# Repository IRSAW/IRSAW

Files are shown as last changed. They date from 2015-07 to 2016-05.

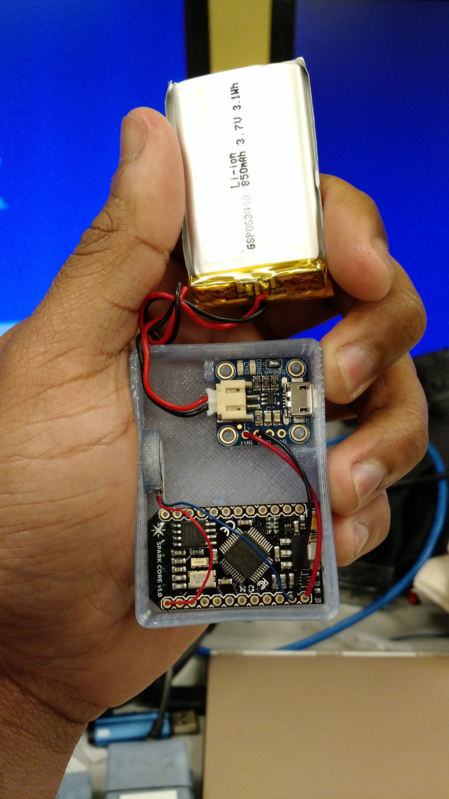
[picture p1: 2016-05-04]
Wearable Components Designs and Files for printing/Actuator Images and Diagrams/Finished Spark Core based actuator box.jpg

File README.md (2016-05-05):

# IRSAW
Intel RealSense Spatial Awareness Wearable 

This project is about augmenting the sense of the visually impaired using a wearable which gives vibrotactile feedback 
on the body to make them aware about their surroundings.  
A depth camera is used to see what is in front of a person and the vibration motors on the body notify the person 
about where the object is in the front based on what the camera sees. 

#This branch of IRSAW is highly modified which a lot of changes.

The changes are listed below

1.	Using Intel RealSense Cross Platform API (librealsense) to capture camera data instead of the DCM and the SDK, you don’t need to install anything to use the camera now.

2.	Ported to Visual Studio 2013. librealsense is not compatible with VS 2012

3.	Ported to Cinder 0.9.0 from 0.8.6

4.	You don’t have to build a Vibration Actuator with a button. All the Vibration Actuators are made the same, but the code uploaded to every single Vibration actuator using the Particle Web interface is different (Just one variable has a different value for every single photon for identification purposes) The toggling of the motors can be done using the Laptop app UI or the TouchOSC app running on Android.

5.	You don’t need to save the IP addresses for the Photons in the router. You only need to save the IP Address of the Laptop running the application in the Router.

6.	Using an android phone  (Also compatible with an iPhone, but not tested)to control the application (For turning specific motors on/off, changing the range of detection) We use an android app called Touch OSC http://hexler.net/software/touchosc https://play.google.com/store/apps/details?id=net.hexler.touchosc_a  

7.	Gradual and Pulsing Vibration - using the app you can change the type of vibration feedback you get on your body. It can be gradual or pulsing based on the distance of the object.

#Getting Started
Download the project from the git repository, Download OpenCV 2.4.9 and Cinder 0.9.0. Set environment Variable for Cinder and OpenCV

Set the following Environment Variables	

Tip: your Cinder root folder is where you Include folder is, for example in my case, 
C:\Dev\cinder_0.9.0_vc2013, so that is the value of my CINDER_ROOT variable
For Open CV it is C:\opencv\build, so that is the value of my OPENCV_ROOT variable

CINDER_ROOT = <Location of you cinder 0.9.0 directory>
OPENCV_ROOT = <Location of your OpenCV directory>

librealsense is added as a submodule, so don’t forget to init and update

In the git bash, enter the following commands

git submodule init
git submodule update

These two commands will clone the librealsense repository in the thirdparty folder.

Open the project IRSAW.sln file in visual studio 2013. In the solution explorer, expand the thirdparty folder. Right click on the realsense-s project and open the project properties of the realsense-s project.

In the properties make the following changes

In debug configuration, go to C/C++ -> Code Generation, and change the Runtime Library to Multi-threaded Debug(/MTd)
In Release configuration, go to C/C++ -> Code Generation, and change the Runtime Library to Multi-threaded (/MT)

Apply and save these changes and then compile and run the application, things should run fine and the application window opens. Pressing ‘v’ on the keyboard toggles the visualizer.

#Setting up the Router
The Laptop and the photons connect to Router.

Once you have setup up an SSID and Password to the router, connect the router to the internet from the router settings.

The Router is dual band, but it doesn’t matter if you connect the laptop to the 2.4GHz or the 5GHz band. In the router settings under WiFi Clients change the IP address of the Laptop to “192.168.0.102” Make sure you reserve this IP address for the Laptop and save it so the laptop always gets assigned with the same IP address. If you change the IP address of the laptop for some reason, you will have to change the Server IP address in the photon code to match the IP address of the laptop and also the IP address for the Touch OSC app on your phone.

No need to assign fixed IP addresses to the phone or the Photons on the router.
Try running ipconfig on the laptop on the command line and confirm the ip address of the Laptop. (Sometimes you have to manually reboot the router for the changes to take effect)

#Touch OSC app configuration
Once you downloaded the touch osc app from the app store, go in Settings->OSC

Change the Host address to the IP address of the laptop “192.168.0.102”

Change the Port (Outgoing) to 3000

Change the Port (Incoming) to 3001

Now in the project repository, go in the PhoneOSC folder and open TouchOSCEditor.exe

Click on Open and navigate to the layouts folder in the PhoneOSC folder and open the SAW_ControlsPulse.touchosc file in the editor

Make sure that your laptop and Android phone are on the same Wifi network (Preferably the router’s wifi) and then click “Sync” in the editor and it will open a window giving instructions.

Now on the phone, in the TouchOSC app’s settings, go to Layout->Add from Editor

Add the IP address of the Laptop where the Editor is running in the Host field and click download.

This will download the IRSAW TouchOSC UI

Make sure you select SAW_ControlSPulse UI from the Layouts on the app and then tap on Done

This will show show you the TouchOSC app running the IRSAW UI to control the main application.

Now given that you phone and laptop are connected to the same WiFi and the application is running on the laptop, you will be able to control the Main application from your phone. You can toggle motors, individually change the detection range for the Top, Middle, Bottom motors from 1 meter to 2 meters. It is at 1.5 meters by default.

#Setting up the photons
The repository has a folder called Particle Photon Code in the file called Photon Code.txt

Important changes in the code

1.	Photons can now have a gradual or a pulsing change of vibration controlled from the touchosc app on the phone

2.	Every photon identifies itself to the server application running on the laptop and that Identification is stored in the char variable called “myName”. The Value in this variable changes for every photon (the values range from 1 through 8 for 8 vibration actuators) 

      //char myName = 1;                        // Top Left

      //char myName = 2;                        // Top Center

      //char myName = 3;                        // Top Right

      //char myName = 4;                        // Middle Left

      //char myName = 5;                        // Middle Center

      //char myName = 6;                        // Middle Right

      //char myName = 7;                        // Bottom Left

      //char myName = 8;                        // Bottom Right

Change the variable value depending on which Vibration Actuator you want to upload the code to.

3. There is no vibration actuator with a physical button to toggle the motors On and Off.

Go to build.particle.io log in, then Create New App and copy and paste the code In the app. The follow the process of flashing the code to photons stated on the particle website
https://docs.particle.io/guide/getting-started/intro/photon/ 

When you flash this code to the photons, the photons will disconnect from the Particle Cloud, so to update the photons again, you will have to put the photons to safe mode and follow the process of uploading the code to the photon again. Instructions on putting the photons to safe mode can be found at docs.particle.io https://docs.particle.io/guide/getting-started/modes/photon/#safe-mode Putting the photon in safe mode will also let you update the code on the photons without factory resetting it.

Once your have flashed the code on all photons, you can now check if the photons connect to the Server application running on the laptop. 

#Known Issues
The vibration actuators freeze on closing the application and then go in deep sleep mode. Cause is yet to be found. But solution is just press the reset button on the photon to bring the photon back to life. 

If the application is not running already, the photons will go to deep sleep and you will be required to wake them up by resetting them by pressing the reset button.

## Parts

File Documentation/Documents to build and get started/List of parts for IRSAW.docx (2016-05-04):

Parts list for Diaktoros

Sr No. | Name | Link
1 | Particle Photon | www.particle.io
2 | Adafruit Micro Lipo w/MicroUSB Jack - USB LiIon/LiPoly charger | http://www.adafruit.com/products/1904
3 | Sparkfun 850 mAh Li-Ion Battery | https://www.sparkfun.com/products/341
4 | Vibration Motor | https://www.sparkfun.com/products/8449
5 | Portable Router | http://www.amazon.com/D-Link-Systems-Portable-Charger-DIR-510L/dp/B00HGLOQ24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
6 | R200
7 | Laptop | Any fan less PC with USB 3.0 is recommended

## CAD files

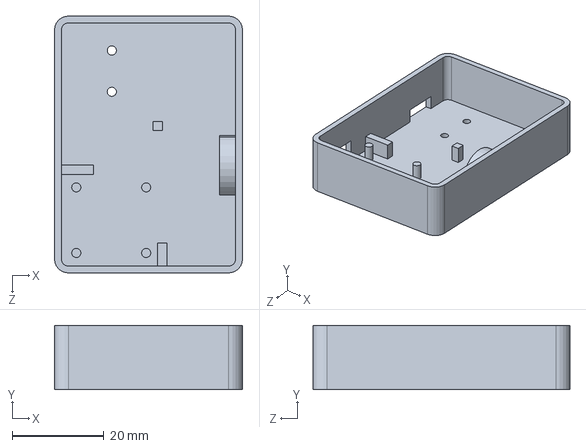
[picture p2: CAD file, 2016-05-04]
Wearable Components Designs and Files for printing/3D Models for printing/Solidworks Files/Photon Actuator Box Base no button.SLDPRT
41.0 x 14.0 x 56.0 mm

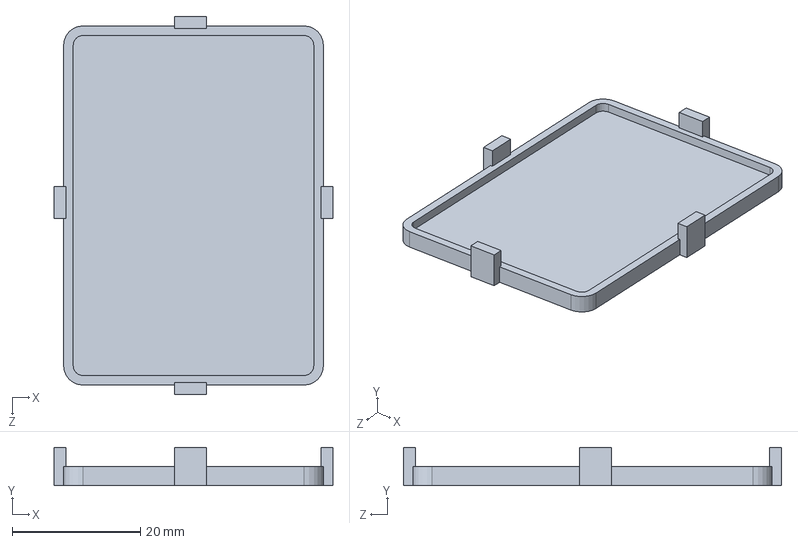
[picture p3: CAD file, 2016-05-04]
Wearable Components Designs and Files for printing/3D Models for printing/Solidworks Files/Photon Actuator Box Lid.SLDPRT
43.5 x 6.00 x 59.0 mm

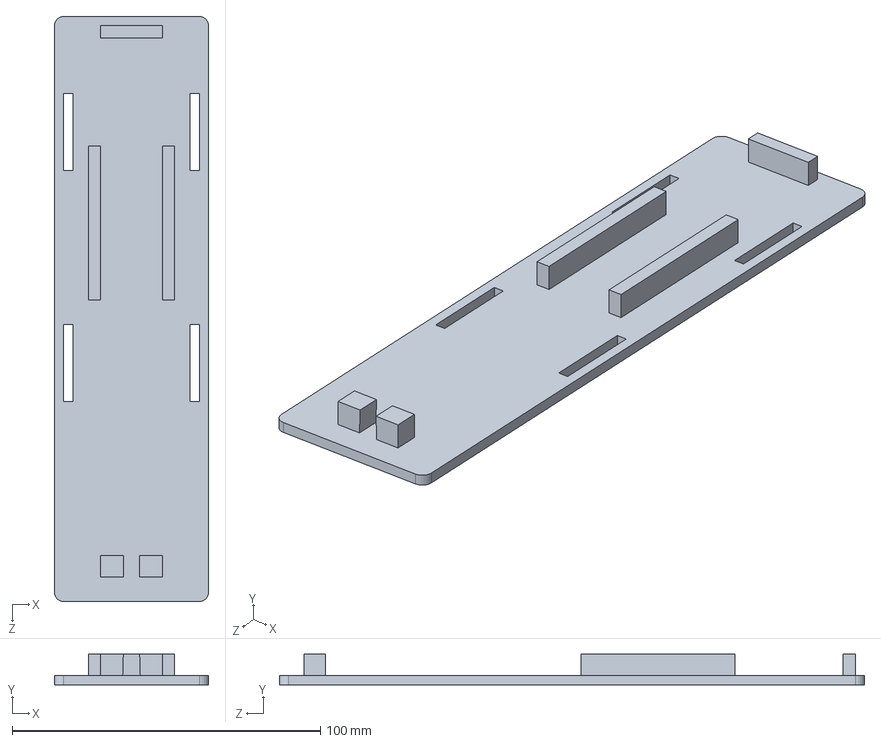
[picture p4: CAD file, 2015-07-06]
Wearable Components Designs and Files for printing/3D Models for printing/Solidworks Files/Camera Mount.SLDPRT
50.0 x 10.0 x 190.0 mm

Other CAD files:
Wearable Components Designs and Files for printing/3D Models for printing/STL/Camera Mount.STL
Wearable Components Designs and Files for printing/3D Models for printing/STL/Photon Actuator Box Base no button .STL
Wearable Components Designs and Files for printing/3D Models for printing/STL/Photon Actuator Box Lid.STL

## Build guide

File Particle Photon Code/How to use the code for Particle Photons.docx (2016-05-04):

How to use the code for Intel RealSense Spatial Awareness Wearable for Particle Photons

How it works

It is a simple TCP client-server handshake where the client announces its identity and the server application knows which client it is. In this case the TCP Server is the laptop and the TCP Clients are Particle Photons. Every particle photon tells the server what vibration actuator it is so the server knows which connect client is which vibration actuator.

This means now the code being uploaded to every single particle photon will be different (change one variable for the Vibration Actuator ID). The particle photons are basically identified with IDs. Following are the IDs used for the specific vibration actuator.

Top Left = 1

Top Center = 2

Top Right = 3

Middle Left = 4

Middle Center = 5

Middle Right = 6

Bottom Left = 7

Bottom Right = 8

The functionality for the physical button is now removed so the physical button which was there on one vibration motor will now not be needed. You can tweak the parameters in the server application with keyboard shortcuts or with the GUI. You don’t have to build a vibration actuator with the button you can build 8 similar vibration actuators with the photons.

The best thing about this is that you now don’t have to set up the fixed IP addresses for the Vibration Actuator in the router. That being said, you still have to set up a fixed IP address for the laptop in the router.

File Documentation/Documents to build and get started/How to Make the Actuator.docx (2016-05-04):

How to make the Vibration Actuator

Parts Needed

Sr No. | Name | Link
1 | Particle photon | www.Particle.io (http://www.spark.io)
2 | Adafruit Micro Lipo w/MicroUSB Jack - USB LiIon/LiPoly charger | http://www.adafruit.com/products/1904
3 | Particlefun 850 mAh Li-Ion Battery | https://www.Particlefun.com/products/341 (https://www.sparkfun.com/products/341)
4 | Vibration Motor | https://www.Particlefun.com/products/8449 (https://www.sparkfun.com/products/8449)

Circuit Diagrams to build Vibration Actuators using Particle Photons

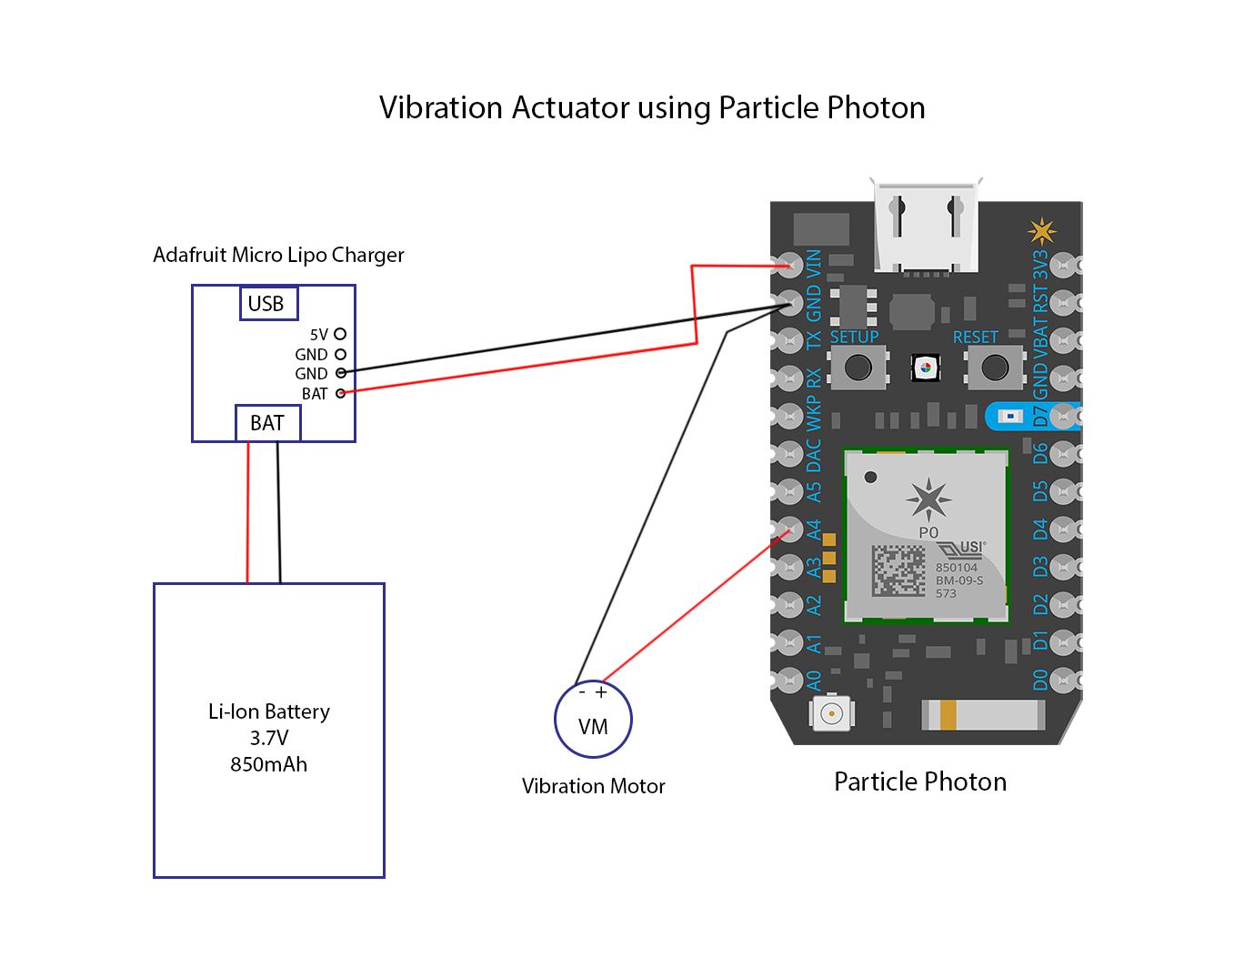
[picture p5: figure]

Instructions to build actuators using Particle Photon

1. Desolder all the pins on the Particle Photons and take them out.
2. Connect the Battery charger to the Particle Photon by connecting the Bat pin to the VIN pin and the GND pin to the GND pin on the Particle Photon. Do not connect the battery to the battery charger while soldering short circuits might happen.
3. Solder the 500mA slot on the battery charger. This will Speed up the charging as it allow more current for charging the battery.
4. Connect the red wire (positive) of the vibration motor to the pin A4 of the Particle Photon and the blue wire (Ground) to the GND pin of the Particle Photon.
5. Once everything is soldered, you can connect the battery to the battery charger and see if the Particle Photon powers on. This can be confirmed by looking at the light on the Particle Photon.
6. If you haven’t used a Particle Photon before, follow the instructions on http://docs.Particle.io/ (http://docs.spark.io/) to learn how to flash the Particle Photon. Important tip, once you have soldered the Particle Photon, only power the Particle Photon using the battery charger. If the battery has no charge you can charge the battery/ power the Photon by any USB power source by connecting the USB cable to the Micro USB port of the battery charger. If you haven’t soldered the Particle Photon, then you can use the micro USB connector on the Particle Photon itself to power the Photon for flashing new code on it.
7. You can find the code for the Particle Photon in the package folder. You can use the Cloud API of Particle to flash the Photons. Once the photon is flashed, we are disconnecting it from the cloud, so to reflash the photon with any updated code, you have to factory reset the Photon to update the code on the Particle Photon. Once you do a factory reset, you can update the Photon as mentioned above. To factory reset the Particle Photon, follow the instructions on the website http://docs.Particle.io/ (http://docs.spark.io/) It is highly recommended to play with the Particle Photon before using it for this project so you get an idea of it’s working.
8. Once the Photon is flashed and the Photon is running without any problems, you can 3d Print the boxes and the lid from the files given in the folder and then put the circuit into the box. It should be assembled as shown in the picture below (Image is of a Particle Core but it will be same for photon).

Put the battery in the box and cover with the lid.

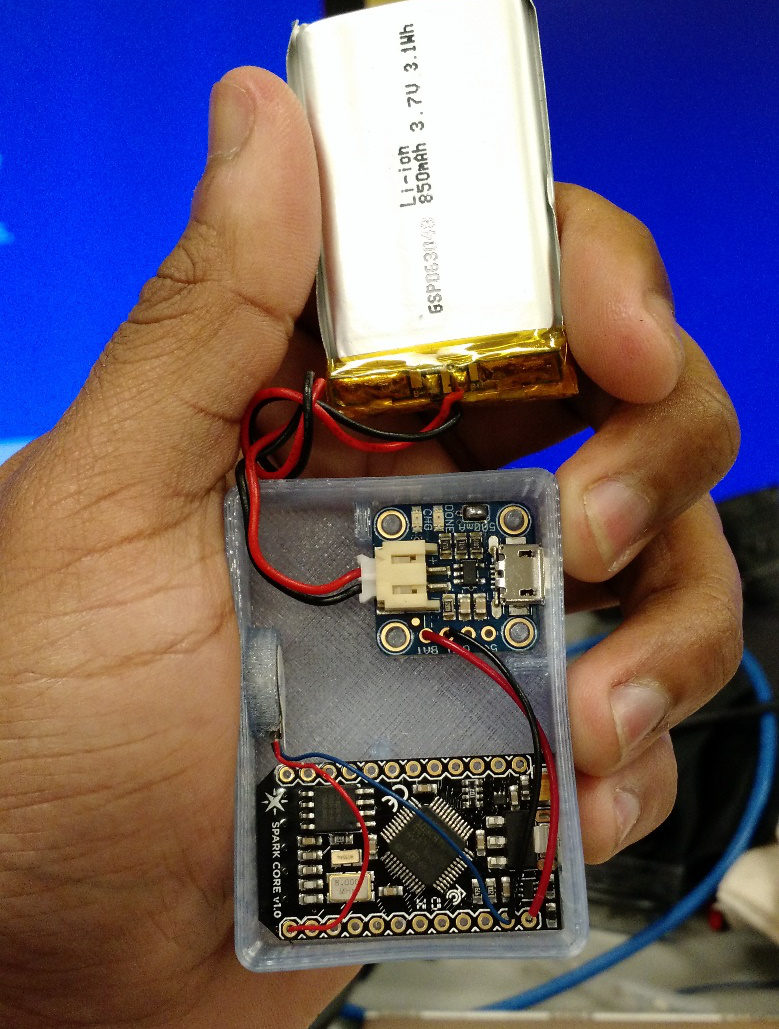
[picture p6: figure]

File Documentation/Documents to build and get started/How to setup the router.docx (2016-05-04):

How to setup the portable router for Intel RealSense Spatial Awareness Wearable

The Laptop connecting to the portable router is assigned fixed IP in the router and is reserved in the router. This is done because the main camera application running on the laptop runs a TCP server and it has to have fixed IP address to which the Particle photon clients connect to. The Vibration Actuators, which run the TCP Client application connect to a TCP server with a specific IP Address.

In the sample code for the Particle Photon (The WiFi enabled microcontroller), The Particle photons connect to a server with a specific address and port number. (IP Address: 198.162.0.102, Port No.: 5555) The laptop needs to be assigned this IP address in the router. This IP address can be changed, but you have to make sure that the IP Address in the Particle Photon Code matches with the reserved IP address for the laptop in the router. So if one changes, the other has to change.

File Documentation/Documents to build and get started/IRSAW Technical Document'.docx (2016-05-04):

Intel RealSense – Spatial Awareness Wearable

What is the project about?

This project is about augmenting the senses of the visually impaired to make them aware of their surroundings and allow them to explore what is around them.

How this works?

This project uses a Depth Camera (Intel RealSense R200) to see how far the objects in its field of view are. The field of view of the camera is divided into 8 sections, 3 top (right, center, left), 3 middle (right, center, left) and 2 bottom (right, left).

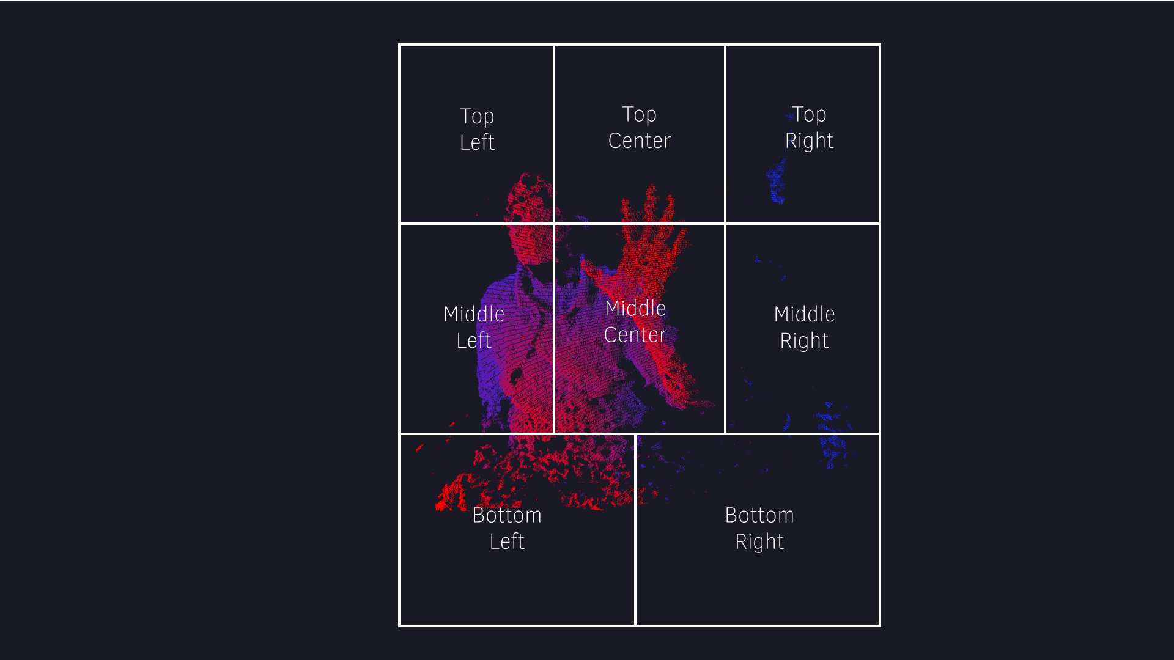
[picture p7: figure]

We find the closest depth pixel in these 8 Sections and track it. The closest depth pixel is the point detected by the camera on the nearest object in that section. Based on the distance of the closest depth pixel in its particular section, we map it to vibration actuators on the body. Closer the object is that particular section, stronger is the vibration, and vice-a-versa. The vibration actuators are placed on 8 parts of the body, 3 on chest (left chest, center chest, and right chest), 3 on hip level (left hip, belly, right hip), and two on legs (left leg and right leg)

The vibration actuator is a vibration motor connected to battery powered WiFi enabled microcontroller (Particle Core). The 8 Sections in the field of view of the camera are mapped to the 8 vibration actuators. The Vibration Actuators communicate with the laptop with the R200 camera over TCP using a portable router.

The laptop, and the 8 vibration actuators are assigned fixed IP addresses in the portable router. The Laptop runs an application which processes the depth data from the camera and functions as a TCP Server to handle the communication with the vibration actuators. The vibration actuators run TCP Client application which connect to the server application with a specific IP address and port number. Based on the fixed IP addresses the Server application knows which Vibration Actuator is for which body part.

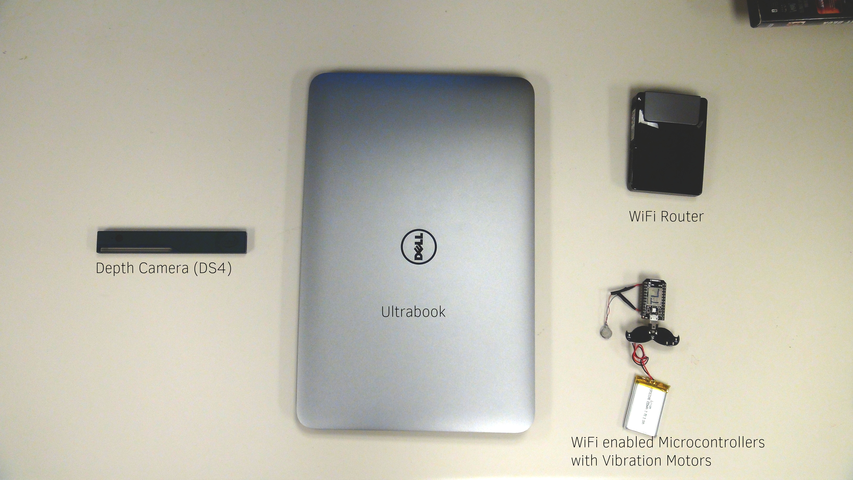
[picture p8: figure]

Parts list

1. X86 based Laptop with USB 3.0 support.
2. Intel RealSense R200 camera (http://click.intel.com/intel-realsense-developer-kit-r200.html)
3. Portable router (http://www.amazon.com/D-Link-Systems-Portable-Charger-DIR-510L/dp/B00HGLOQ24)
4. Particle Core/photon (https://store.particle.io/)
5. Vibration Motors (https://www.sparkfun.com/products/8449)
6. Lipo batteries (https://www.sparkfun.com/products/341)
7. Micro Lipo charger (http://www.adafruit.com/product/1904)
8. Wires for connection

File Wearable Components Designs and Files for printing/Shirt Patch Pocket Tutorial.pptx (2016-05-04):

## Patch Pocket Tutorial

You will need –
Fabric, a ruler (see through plastic is best), a sewing machine, an iron, pins, scissors, paper and pens.
Some tips –
Wash fabrics before sewing to prevent shrinking when washed. Read all the instructions before sewing! Make sure you cut the pattern with the right grain of the fabric. This is very important if you are using stretchy fabric. The stretch should go from side to side, not from top to bottom. Use a new, sharp needle in your sewing machine. If you are sewing with stretchy fabric, it’s best to use a jersey or ball point needle. These are made especially for stretchy fabric and will minimize snagging or thread tension issues. Use more pins if you need to and sew slowly.

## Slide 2

1.
Make a pattern for your pocket. If you need to fit a specific object inside of it, this is how you do it. Measure the length and width of your object and draft a rectangle with these measurements onto a piece of paper. Use a ruler and make sure to square off your edges into right angles so that it isn’t crooked. Extend the lines out as shown.

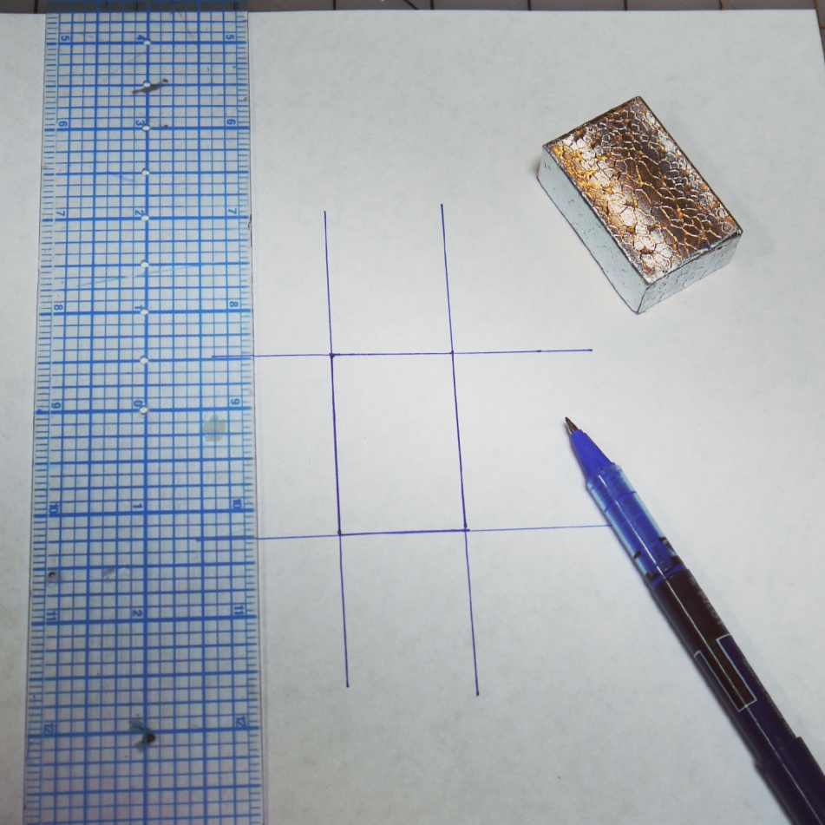
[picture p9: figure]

2.
Now measure the depth of your object. If it is flat, this won’t be much. If it’s very deep, we will need to add ex tra space to the pocket. Add the depth measurement around all sides of your rectangle using the ruler. I’ve marked the new lines in yellow here.

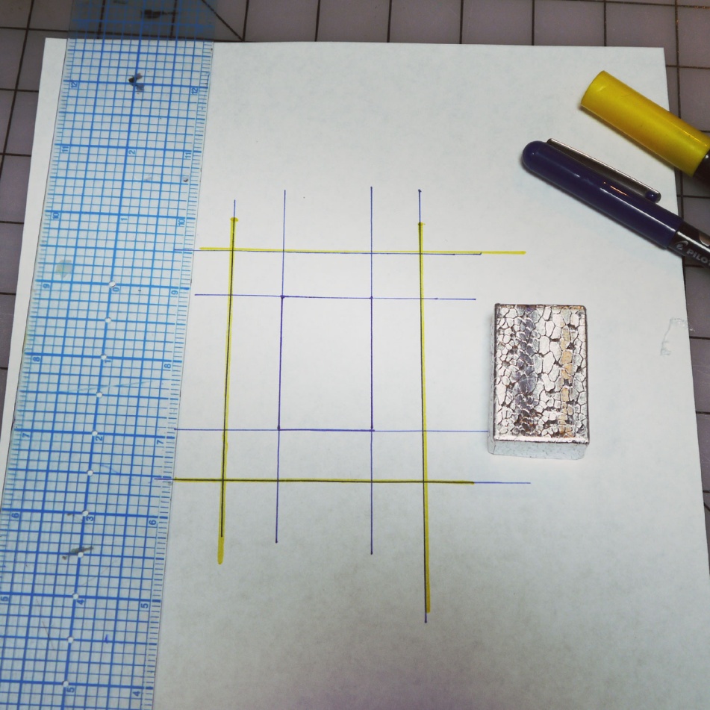
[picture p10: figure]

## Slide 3

3.
Now we are going to add seam allowances. I use 3/8 of an inch. Add this amount all around the outside of the last set of lines. I’ve made the lines here in pink to illustrate this. At the top, add another 3/8 as shown. This is so we can fold the top down twice, encasing the raw fabric edge and making a nice clean finish.

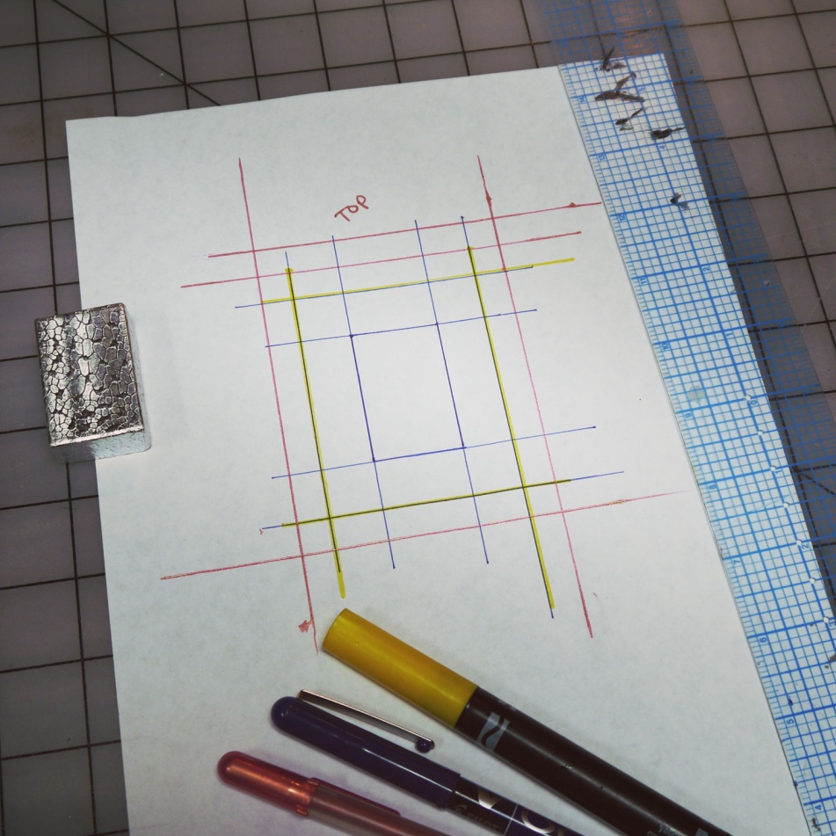
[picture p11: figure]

4.
Here I’ve labeled the top of the pattern, and which lines will be folded in on the pocket. It helps to be able to look back at the pattern if y ou need to remember what is what.

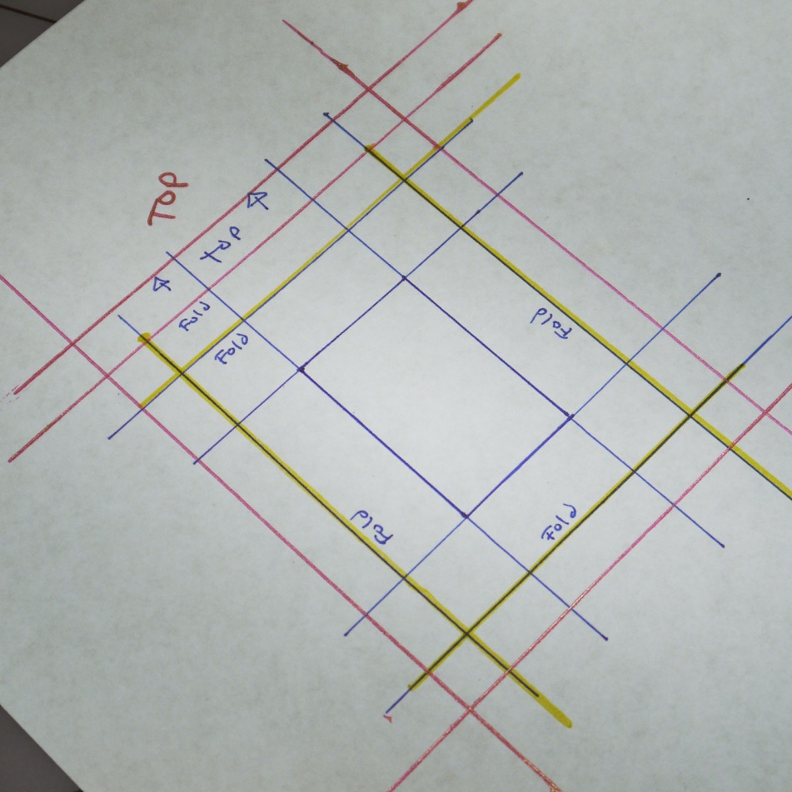
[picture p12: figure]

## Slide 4

5.
Now cut the pattern out. This is what it will look like – it’s just a rectangle. You can make a pattern by just adding all the necessary measurements and drawing a rectangle, but if you are new to sewing it will help to have a pattern with markings to refer to.

6.
This is what the pattern looks like when all of the seam allowances are folded in. This is what size the finished pocket will be.

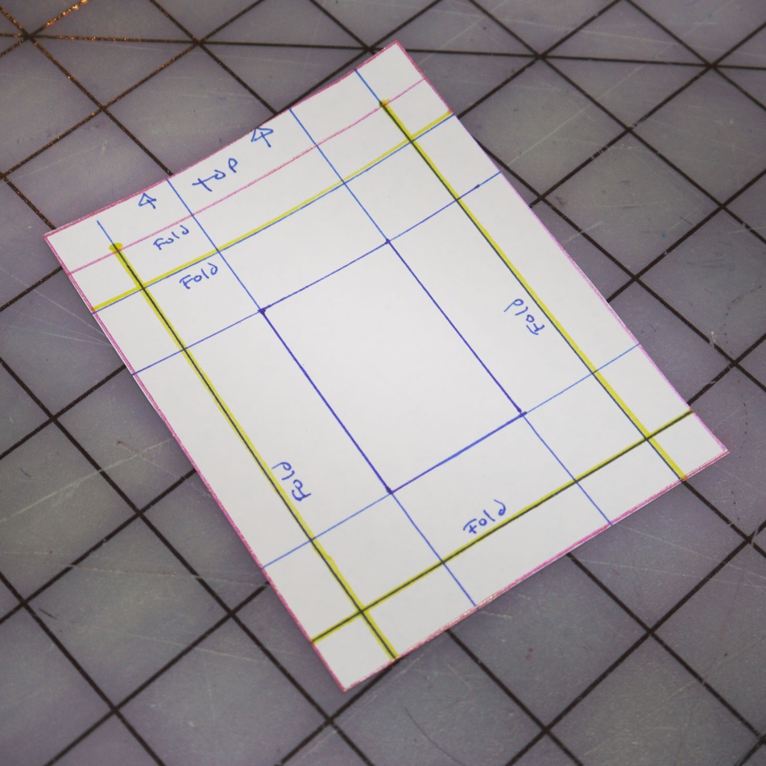
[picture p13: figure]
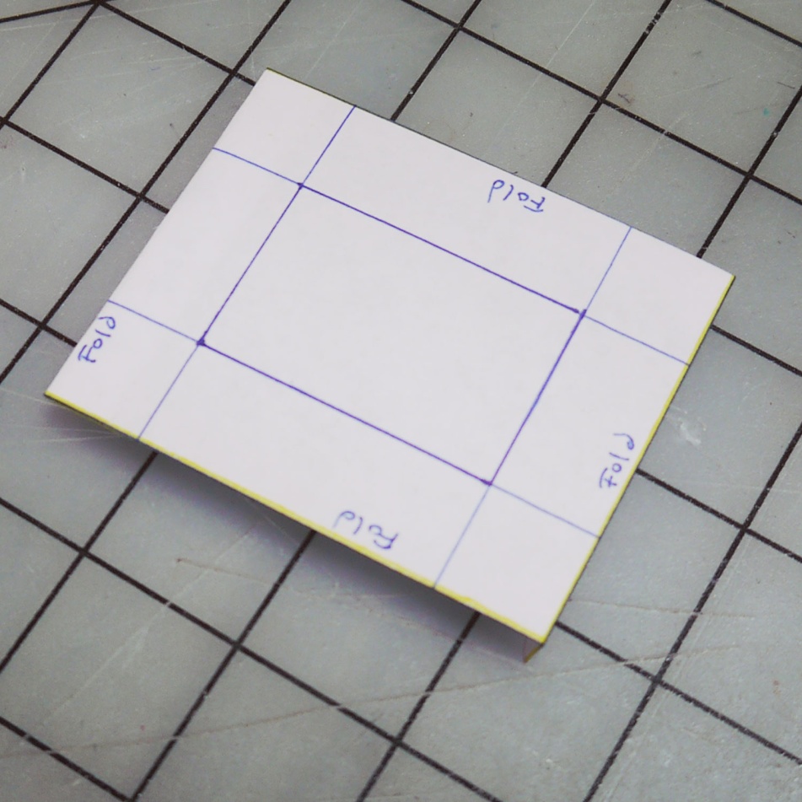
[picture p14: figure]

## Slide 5

7.
Now pin your pattern onto your fabric and cut out around it. Make sure that the pattern is going with the grain of the fabric. This means the top edge will be perpendicular to the selvedge .What you will have is an unmarked rectangle. If it helps you, you can use the ruler to trace on the seam allowance lines so you will know where to fold the pocket.

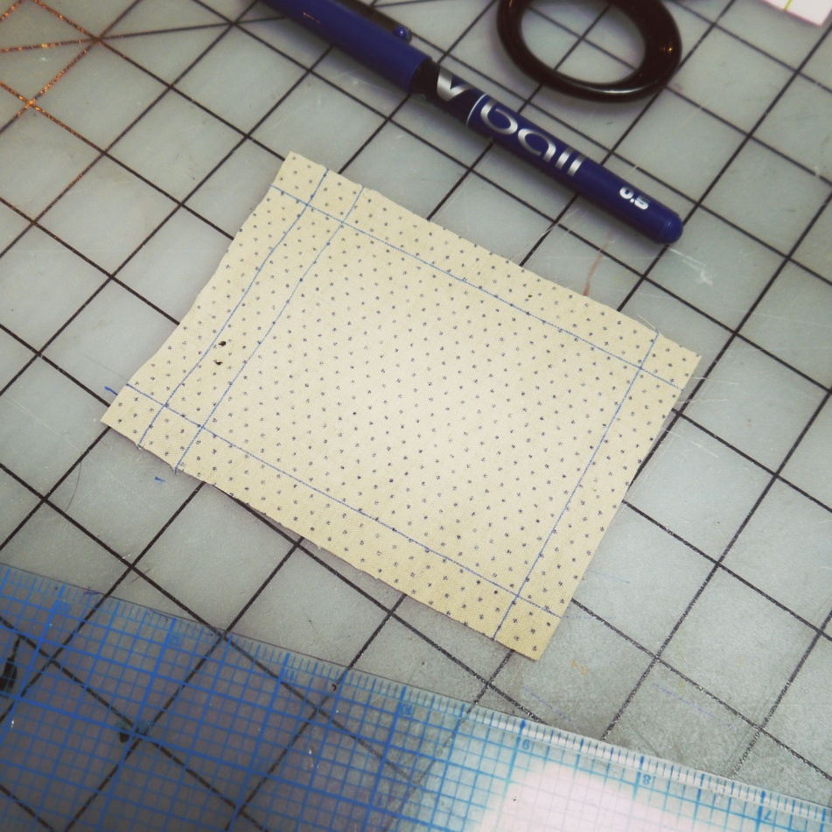
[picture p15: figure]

8.
Now it’s time to finish the top edge of the pocket. Fold down the first fold line of the pocket top edge and press it with an iron. Then fold it again and press it so you have a double fold, with the raw edge of the fabric being sandwiched inside.

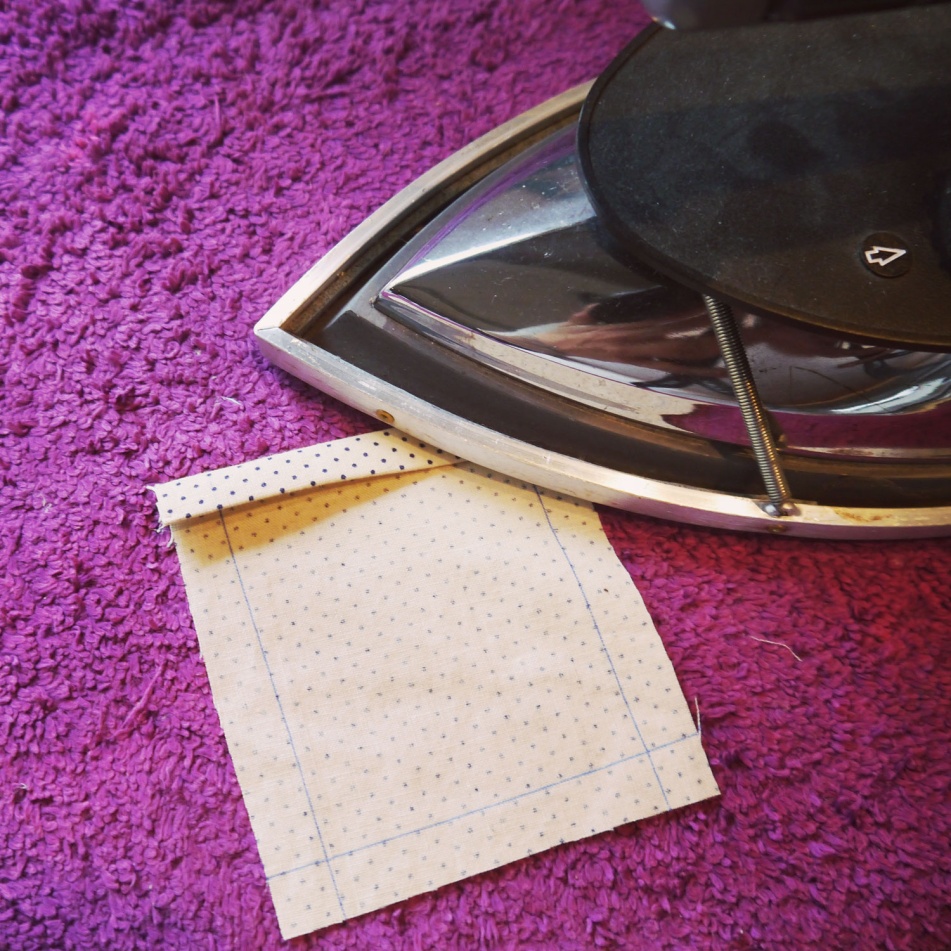
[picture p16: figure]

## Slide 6

9.
Now sew across the top edge to secure it.

10.
Next, fold in and press the other seam allowances. Do the bottom edge first, and then the two sides.

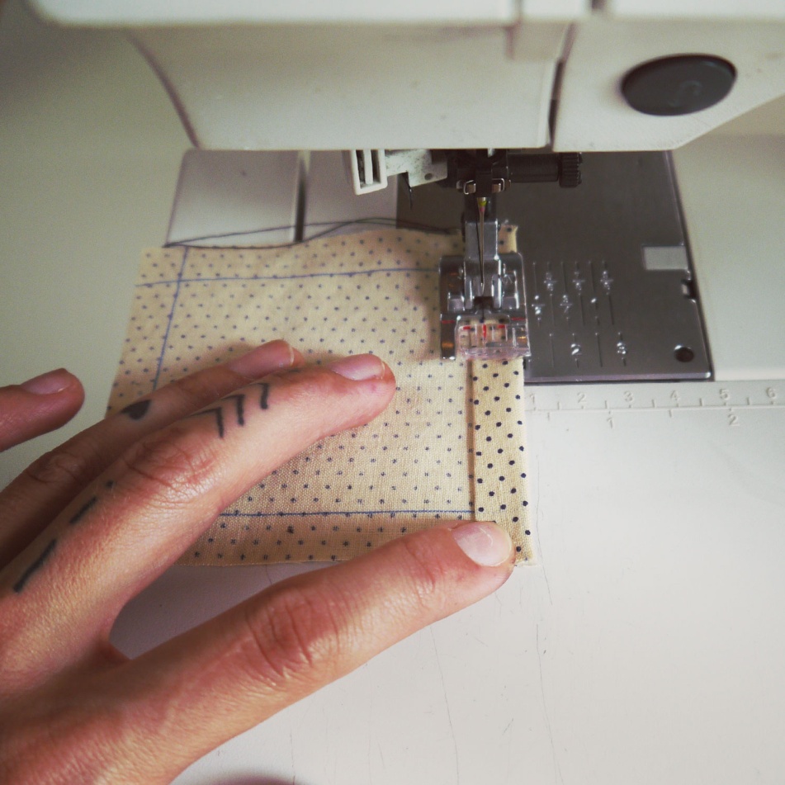
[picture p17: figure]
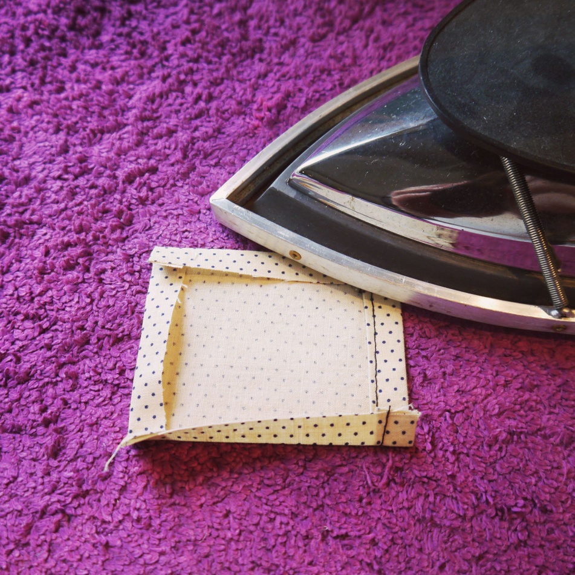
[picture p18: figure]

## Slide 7

11.
Pin the folded and pressed pocket piece onto the fabric you want to sew it onto. If this is a garment, try it on first and mark with a pencil where it should go. Use a ruler or measuring tape to make sure it’s straight.

12.
Then sew around the remaining three sides of the pocket, leaving the top edge open. Make sure to backstitch at the beginning and end of your seam so that it won’t unravel. Now your pocket is finished!

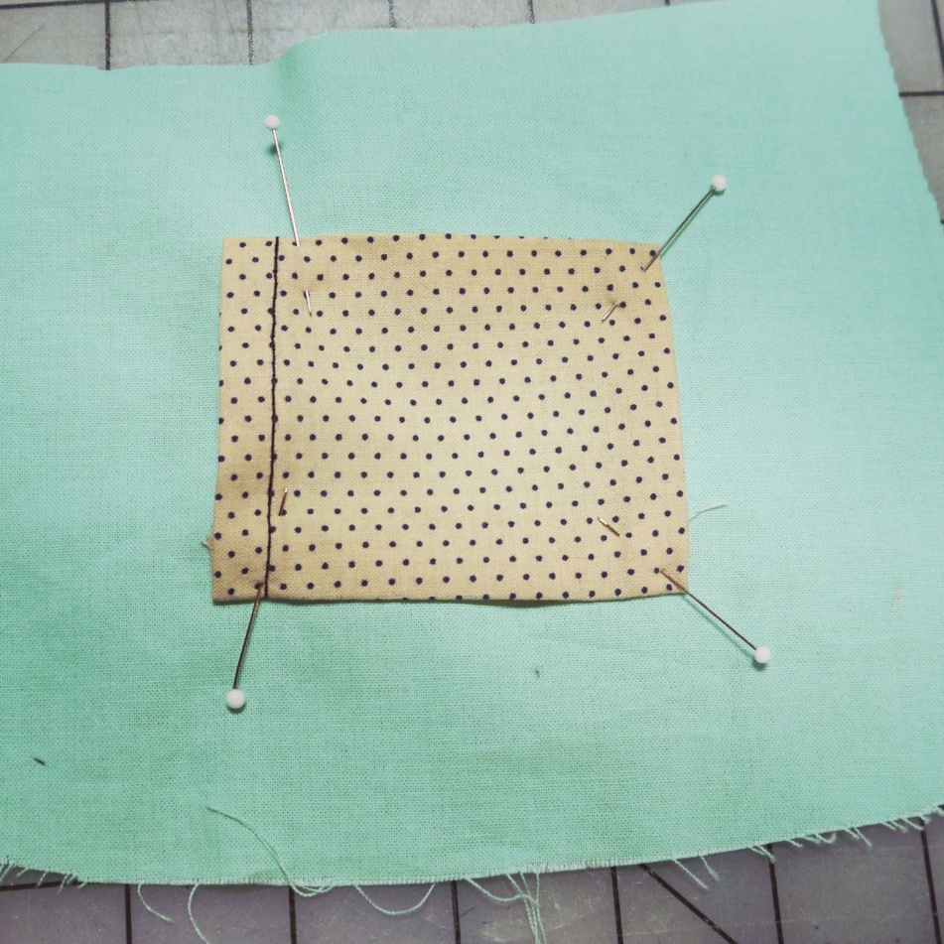
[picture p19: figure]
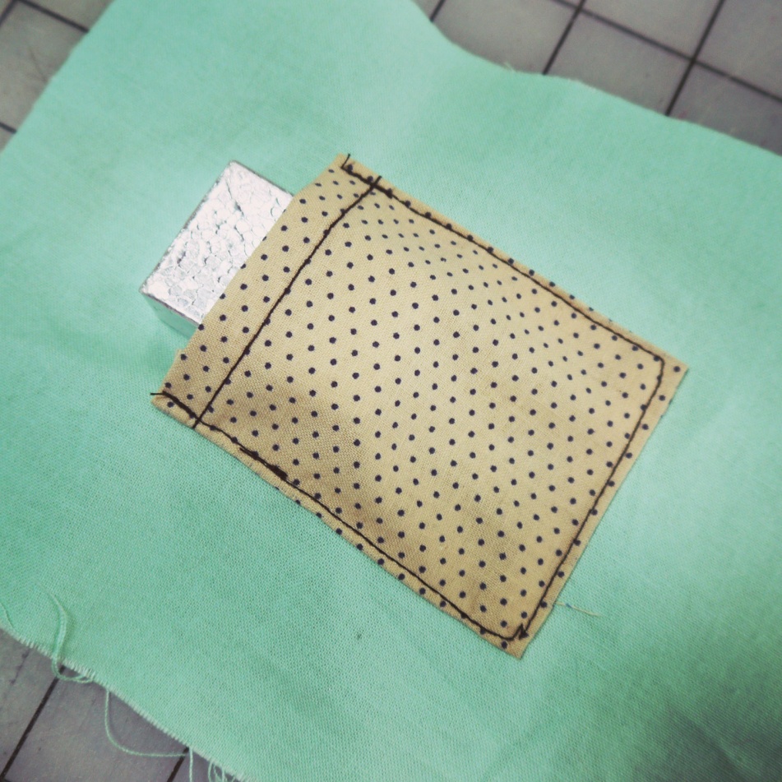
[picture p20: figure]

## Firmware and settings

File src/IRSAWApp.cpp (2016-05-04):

#include "cinder/app/App.h"
#include "cinder/app/RendererGl.h"
#include "cinder/gl/gl.h"
#include "cinder/params/Params.h"
#include "cinder/ip/Resize.h"
#include "cinder/gl/Texture.h"
#include "cinder/gl/TextureFont.h"
#include "cinder/ImageIo.h"
#include "cinder/Surface.h"
#include "cinder/Text.h"
#include "cinder/Utilities.h"
#include "cinder\CinderMath.h"

#include <functional>

//OSC
#include "cinder/System.h"
#include "OscSender.h"
#include "OscListener.h"

//OpenCV
#include "opencv2/imgproc/imgproc.hpp"
#include "opencv2/highgui/highgui.hpp"

#include <iostream>
#include <stdlib.h>
#include <sstream>
#include <iomanip>
#include <thread>
#include <algorithm>

// for Winsock
#include<stdio.h>
#include<winsock2.h>

#pragma comment(lib, "ws2_32.lib") //Winsock Library

#include <librealsense/rs.hpp>

using namespace ci;
using namespace ci::app;
using namespace std;
using namespace cv;


class IRSAWApp : public App {
  public:

	//Variables for holding OSC data
	osc::Sender		oscStatusReturn;
	osc::Listener 	oscListener;
	std::string		host;
	int 			sendingPort;

	//variables used to convert the depth buffer visualize it.
	Channel16u		  mDepthChannel;
	gl::Texture2dRef  mDepthTex;
	int			mDepthW, mDepthH; // These variables store the height and depth of the raw depth buffer

	//librealsense
	rs::context ctx;
	rs::device * dev;

	// Booleans for params for togging specific motor, all the motors, vertical horizontal camera configuration
	bool verticalConfig;
	bool areAllMotorsOn;
	bool isTROn;
	bool isTCOn;
	bool isTLOn;
	bool isMROn;
	bool isMCOn;
	bool isMLOn;
	bool isBROn;
	bool isBLOn;
	bool isTopOn;
	bool isMiddleOn;
	bool isBottomOn;
	bool isCenterOn;

	//Pulsing and gradual toggles
	bool isPulsingOn;
	bool isPulsingOnSent;
	//int pulsingState, gradualState;
	char pulsingOn, gradualOn;

	//Variables for receiving data
	char whichNumber[1];
	int recvResult;
	int clientNumber;

	//variable for toggling rendering of visualizer.
	bool isVisualizerVisible;

	//these are parameters to set the distance of detection. The distance can be specified millimeters
	int topDetectionThreshold;
	int middleDetectionThreshold;
	int bottomDetectionThreshold;


	// variables for initial Server message to clients on connection
	char lightsON;

	//chars to store data to be sent to the cores
	char cdv1;
	char cdv2;
	char cdv3;
	char cdv4;
	char cdv5;
	char cdv6;
	char cdv7;
	char cdv8;

	char zero;


	// variables to store the position of the client  in the client_socket[] array

	int TLPos;
	int TCPos;
	int TRPos;
	int MLPos;
	int MCPos;
	int MRPos;
	int BLPos;
	int BRPos;
	int ClientPos;

	//storing depth pixels as unsigned int 8 bit.
	uint8_t clampedPixel0;
	uint8_t clampedPixel1;
	uint8_t clampedPixel2;
	uint8_t clampedPixel3;
	uint8_t clampedPixel4;
	uint8_t clampedPixel5;
	uint8_t clampedPixel6;
	uint8_t clampedPixel7;
	uint8_t clampedPixel8;

	//stores the depth image
	uint16_t * depth;



	// matrix pointer to do openCV operations
	Mat src;

	//element is used to specify the kernel size for the erode function. changing the kernel size  will alter the result of erosion
	Mat element;

	int closestDepthValue1;   //for top left
	int closestDepthValue2;   //for top right
	int closestDepthValue3;   //for middle left
	int closestDepthValue4;   // for middle right
	int closestDepthValue5;   // for bottom left
	int closestDepthValue6;   // for bottom right
	int closestDepthValue7;    // for top center
	int closestDepthValue8;    // for middle center

	// ints to store the current depth values of the pixel being processed.
	int currentDepthValue1;
	int currentDepthValue2;
	int currentDepthValue3;
	int currentDepthValue4;
	int currentDepthValue5;
	int currentDepthValue6;
	int currentDepthValue7;
	int currentDepthValue8;

	//Parameters to set the bounds of the sections
	int HoT;    //Height of Top
	int HoM;	//Height of Middle
	int HoB;	//Height of Bottom
	int WoR;	//Width of Right
	int WoC;	//Width of Center
	int WoL;	//Width of Left
	int WoBR;	//Width of Bottom Right
	int WoBL;	//Width of Bottom Left

	// Rectangles drawn by on Screen representing every single section.
	Rectf TLzone;
	Rectf TCzone;
	Rectf TRzone;
	Rectf MLzone;
	Rectf MCzone;
	Rectf MRzone;
	Rectf BLzone;
	Rectf BRzone;

	// Variables for Winsock
	WSADATA wsa;
	SOCKET master, new_socket, client_socket[30], s;
	struct sockaddr_in server, address;
	int max_clients, activity, addrlen, i;

	//set of socket descriptors
	fd_set readfds;
	timeval waitTime; //  wait time for the server to wait for client connections

	//For Cinder Params
	params::InterfaceGlRef	mParams;

	void setup() override;
	void update() override;
	void draw() override;
	void shutdown();
	void toggleTopMotors();
	void toggleMiddleMotors();
	void toggleBottomMotors();
	void toggleCenterMotors();
	void toggleAllMotors();
	void toggleVerticalHorizontal();
	void keyDown(KeyEvent event);

	//map and clampToByte function map the depth values from 0 to 256 and convert that data into byte
	float map(float value, float inputMin, float inputMax, float outputMin, float outputMax);
	uint8_t clampToByte(float value, float min, float max);
};

void IRSAWApp::keyDown(KeyEvent event)
{
	// Pressing q will quit the program
	if ((event.getChar() == 'q') || (event.getChar() == 'Q'))
	{
		closesocket(client_socket[TRPos]);
		closesocket(client_socket[TCPos]);
		closesocket(client_socket[TLPos]);
		closesocket(client_socket[MRPos]);
		closesocket(client_socket[MCPos]);
		closesocket(client_socket[MLPos]);
		closesocket(client_socket[BRPos]);
		closesocket(client_socket[BLPos]);
		WSACleanup();
		quit();
	}

	//pressing h will switch toggle verticle/horizontal camera config
	if ((event.getChar() == 'H') || (event.getChar() == 'h'))
	{
		toggleVerticalHorizontal();
	}

	//pressing v will switch toggle visiblility of visualizer
	if ((event.getChar() == 'V') || (event.getChar() == 'v'))
	{
		isVisualizerVisible = !isVisualizerVisible;
	}

	//pressing t will toggle the top row of motors
	if ((event.getChar() == 'T') || (event.getChar() == 't'))
	{
		toggleTopMotors();
	}

	//pressing b will toggle the bottom row of motors
	if ((event.getChar() == 'B') || (event.getChar() == 'b'))
	{
		toggleBottomMotors();
	}

	//pressing m will toggle the middle row of motors
	if ((event.getChar() == 'M') || (event.getChar() == 'm'))
	{
		toggleMiddleMotors();
	}

	//pressing c will toggle the center column of motors
	if ((event.getChar() == 'C') || (event.getChar() == 'c'))
	{
		toggleCenterMotors();
	}

	//pressing o will toggle all the motors
	if ((event.getChar() == 'o') || (event.getChar() == 'O'))
	{
		toggleAllMotors();
	}
}
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

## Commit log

2015-07-06 Changed the particle core and photon code. Added the header to the code
    [Actuator Box Base No Button.STL, Actuator Box Lid.SLDPRT, Actuator Box Lid.STL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]
2015-07-07 Added documents to build the actuators and setup routers
2015-07-07 adding docs and images to build actuators and setup the router
2016-05-04 librealsense suppor
    [Camera Mount.SLDPRT, Camera Mount.STL, Photon Actuator Box Base no button .STL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]
2016-05-05 Removed unneeded 3D print files
    [Actuator Box Base No Button.STL, Actuator Box Lid.SLDPRT, Actuator Box Lid.STL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]
